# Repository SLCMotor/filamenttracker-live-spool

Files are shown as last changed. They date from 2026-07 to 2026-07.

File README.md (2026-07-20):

# FilamentTracker Live Spool

FilamentTracker Live Spool turns a Raspberry Pi into a local-network spool scale,
NFC/RFID station, touchscreen dashboard, and hardware API for FilamentTracker.
The Android application and FilamentTracker Server remain the inventory systems
of record; Live Spool stores no second spool inventory database.

> [!IMPORTANT]
> Live Spool is designed for a trusted home or workshop LAN. It is not hardened
> for direct Internet exposure. Do not port-forward its API.

## Features

- live spool weight with NAU7802, HX711, or mock scale backends
- PN532 NFC read, verified write, and logical erase operations over I2C
- FilamentTracker JSON/NDEF spool tags and Bambu Lab RFID interoperability
- temporary Android-triggered NFC write sessions
- combined current-spool state without a local inventory database
- touchscreen dashboard, calibration wizard, diagnostics, and settings
- REST API for FilamentTracker Android and FilamentTracker Server
- external configuration and calibration storage designed to survive updates
- idempotent installer, preservation-first updater, and safe uninstaller

## Hardware

Tested appliance:

- Raspberry Pi 5 with 64-bit Raspberry Pi OS Trixie
- ELECROW 7-inch 1024×600 touchscreen
- PN532 NFC reader in I2C mode at `0x24`
- NAU7802 load-cell ADC at `0x2A`
- 5 kg four-wire load cell

Also supported in software:

- HX711 load-cell ADC using BCM GPIO pins (defaults: data 5, clock 6)
- mock hardware on Linux development systems

Raspberry Pi 5 running 64-bit Raspberry Pi OS Trixie is the reference and tested platform. Raspberry Pi 4 with a
64-bit Raspberry Pi OS is expected to work but has not yet received the same
hardware validation. See [Hardware](docs/HARDWARE.md) before wiring anything.

## Hardware documentation

The complete build package is under [`hardware/`](hardware/README.md):

| Guide | Purpose |
| --- | --- |
| [Bill of Materials](hardware/docs/01_Bill_of_Materials.md) | Components, quantities, and build notes |
| [Wiring Diagram](hardware/docs/02_Wiring_Diagram.png) | Raspberry Pi, NFC, scale ADC, and load-cell connections |
| [Assembly Guide](hardware/docs/03_Assembly_Guide.png) | Mechanical assembly overview |
| [Print Plates](hardware/docs/04_Print_Plates.png) | Printable parts and plate organization |
| [Calibration Guide](hardware/docs/05_Calibration_Guide.md) | Tare, calibration, verification, and troubleshooting |

The recommended printable is the multi-plate [`FilamentTracker_Live_Spool.3mf`](hardware/printable/FilamentTracker_Live_Spool.3mf).
An [STL package](hardware/printable/FilamentTracker_Live_Spool_STL.zip) is also
provided for OrcaSlicer, PrusaSlicer, Cura, and other slicers.

The enclosure is modified from MartinNYHC's SpoolBuddy design under CC BY 4.0.
See the [hardware attribution and modification record](hardware/ATTRIBUTION.md).

## Wiring summary

PN532 and NAU7802 intentionally share I2C bus 1:

| Signal | Raspberry Pi | PN532 | NAU7802 |
| --- | --- | --- | --- |
| 3.3 V | Pin 1 or 17 | VCC/VIN* | VCC/VIN* |
| Ground | Any GND | GND | GND |
| SDA1 | GPIO 2 / pin 3 | SDA | SDA |
| SCL1 | GPIO 3 / pin 5 | SCL | SCL |

\* Confirm the voltage requirement printed on your exact breakout board.

Default HX711 wiring:

| HX711 | Raspberry Pi |
| --- | --- |
| VCC | 3.3 V |
| GND | Ground |
| DAT / DOUT | GPIO 5 / pin 29 |
| CLK / SCK | GPIO 6 / pin 31 |

Load-cell wire colors are not universal. For the tested cell, red is `E+`, black
is `E-`, green is `A+`, and white is `A-`. Verify your load-cell datasheet.

## Install

```bash
git clone https://github.com/SLCMotor/filamenttracker-live-spool.git
cd filamenttracker-live-spool
sudo ./install.sh
```

The installer checks the platform, installs system packages, enables I2C, creates
a virtual environment, installs the service and optional kiosk autostart, and
verifies the local API. Existing configuration and calibration are preserved.
New installs use safe mock-hardware defaults; select `nau7802` or `hx711` in:

```text
/etc/filamenttracker-live-spool/config.yaml
```

Then restart:

```bash
sudo systemctl restart live-spool-agent
curl --fail http://127.0.0.1:8001/status
```

Detailed instructions: [Installation](docs/INSTALL.md).

## Configuration

Configuration precedence is environment variables, external YAML, then the
repository development defaults. Appliance files are:

```text
/etc/filamenttracker-live-spool/config.yaml
/etc/filamenttracker-live-spool/live-spool.env
/var/lib/filamenttracker-live-spool/calibration.json
```

Configurable values include device name/location, API host and port, log level,
runtime directory, scale backend and GPIO pins, I2C addresses, development mode,
mock hardware, and local system-control availability. See
[Configuration](docs/CONFIGURATION.md).

## REST API

Common endpoints:

| Method | Path | Purpose |
| --- | --- | --- |
| GET | `/health` | process health without requiring hardware |
| GET | `/status` | combined appliance and hardware status |
| GET | `/weight` | current scale reading |
| GET | `/nfc` | NFC reader and current tag state |
| GET | `/spool/current` | combined live scale and tag snapshot |
| POST | `/nfc/write` | start a temporary verified write session |
| POST | `/nfc/erase` | logically erase a writable NTAG |
| GET/POST | `/calibration/*` | inspect or perform calibration |

Mock routes exist only in development/mock mode. System power routes are disabled
by default. The API intentionally has no cloud discovery or remote-access layer.
See the complete [REST API](docs/API.md) and
[Android integration](docs/ANDROID_INTEGRATION.md).

## Technician menu

On the touchscreen, press and hold the **Filament Tracker / Live Spool** title
in the upper-left corner for about one second. A progress indicator fills during
the 900 ms hold, then the Technician Menu opens.

The menu provides quick access to:

- Dashboard
- Diagnostics
- Calibration
- Settings, including restart, reboot, and shutdown controls

Tap the **×** button or the area outside the menu to close it. The same gesture
works with a mouse by holding the primary button over the title. If the gesture
is unavailable, open `/diagnostics`, `/calibration-wizard`, or `/settings`
directly in the appliance browser.

## Calibration

Open `http://<live-spool-host>:8001/calibration-wizard`, remove all weight, tare,
place an accurately known weight, enter its mass, and verify the result. The
calibration file is written atomically under `/var/lib` and is not overwritten
by installation or updates.

## Photos

<table>
<tr>
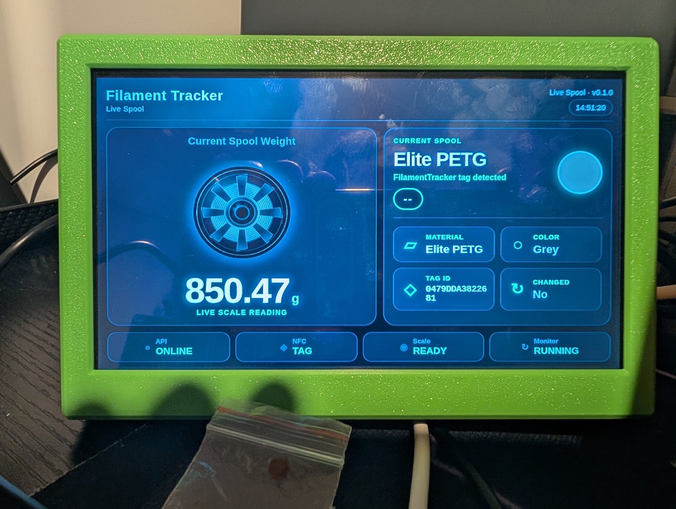
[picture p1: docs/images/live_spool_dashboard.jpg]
Live Spool touchscreen dashboard
<td><br><strong>Touchscreen dashboard</strong></td>
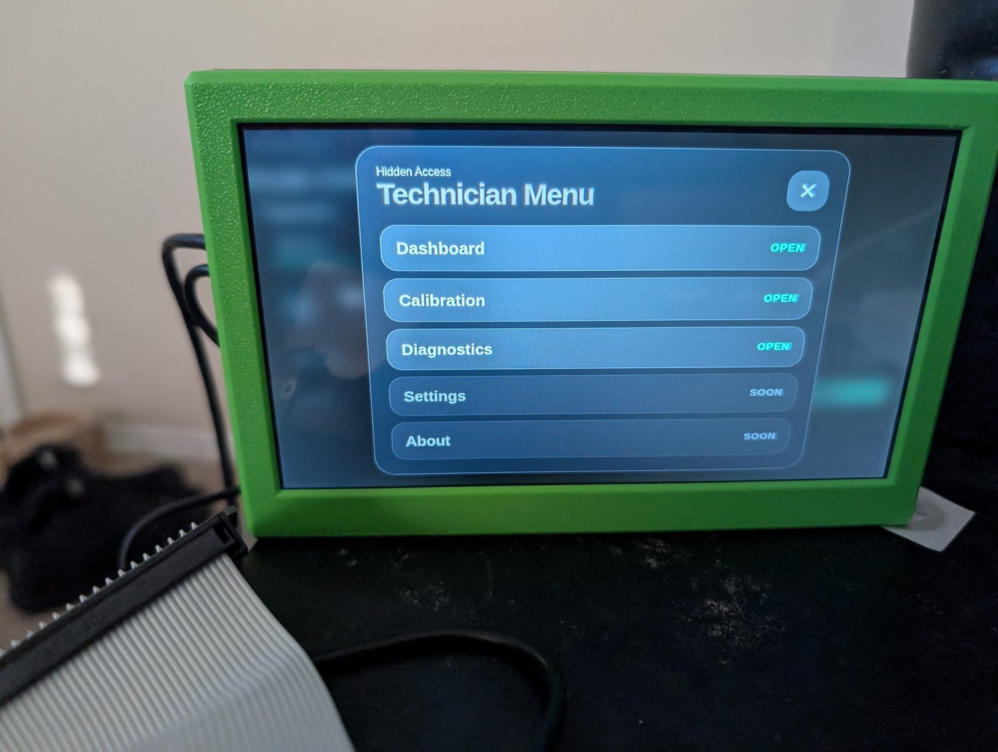
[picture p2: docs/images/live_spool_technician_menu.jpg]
Live Spool technician menu
<td><br><strong>Technician menu</strong></td>
</tr>
<tr>
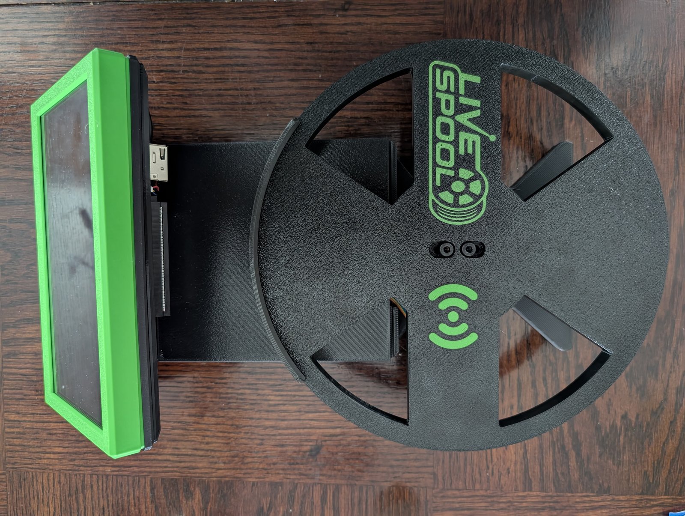
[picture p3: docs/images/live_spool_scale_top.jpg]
Completed Live Spool scale and touchscreen
<td><br><strong>Completed appliance</strong></td>
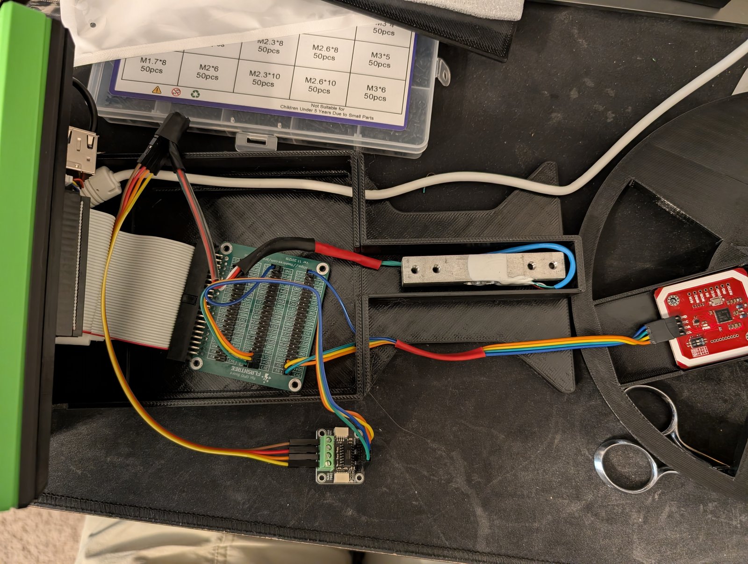
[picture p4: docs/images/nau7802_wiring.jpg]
NAU7802 and PN532 wiring inside the appliance
<td><br><strong>NAU7802 and PN532 wiring</strong></td>
</tr>
</table>

See the [complete hardware gallery](docs/GALLERY.md) for the display, Raspberry Pi,
load cell, PN532, NAU7802, HX711, breakout board, and wiring photographs.
Publication copies are resized and contain no camera EXIF or GPS metadata.

## Updating

```bash
cd filamenttracker-live-spool
sudo ./scripts/update.sh
```

The updater requires a clean checkout, creates a timestamped configuration and
calibration backup, performs a fast-forward-only pull, updates dependencies,
restarts the service, and verifies health. It never pushes changes.

## Troubleshooting

Start with:

```bash
sudo systemctl status live-spool-agent --no-pager -l
sudo journalctl -u live-spool-agent -n 100 --no-pager
i2cdetect -y 1
curl --fail http://127.0.0.1:8001/health
```

Expected I2C addresses are `24` for PN532 and `2a` for NAU7802. See
[Troubleshooting](docs/TROUBLESHOOTING.md).

## Known limitations

- Raspberry Pi 5 is the only fully validated Pi model today.
- The API assumes a trusted LAN and must not be exposed directly to the Internet.
- Bambu RFID support is read-only and depends on successful tag authentication.
- NFC writing targets compatible NTAG/NDEF tags; tag capacity varies.
- Kiosk behavior varies among Raspberry Pi OS desktop/display-server releases.
- Scale accuracy depends heavily on mechanical construction and calibration.

## Roadmap

- validate Raspberry Pi 4 and additional displays
- improve guided hardware selection during installation
- add authentication for optional administrative operations
- expand Android and FilamentTracker Server integration tests
- validate additional enclosure variants and publish editable CAD source when available
- add upgrade rollback assistance and packaged releases

## Contributing and security

See [CONTRIBUTING.md](CONTRIBUTING.md), [SECURITY.md](SECURITY.md), and
[CODE_OF_CONDUCT.md](CODE_OF_CONDUCT.md). Please report security issues privately
rather than opening a public issue.

## License

Software and original project documentation: MIT. See [LICENSE](LICENSE) and
[THIRD_PARTY_NOTICES.md](THIRD_PARTY_NOTICES.md). The derivative printable
enclosure is separately licensed under CC BY 4.0; see
[hardware/ATTRIBUTION.md](hardware/ATTRIBUTION.md).
FilamentTracker and Bambu Lab names belong to their respective owners; this
project is an independent interoperability tool.

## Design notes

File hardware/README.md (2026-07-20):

# FilamentTracker Live Spool Hardware

This directory contains the build documentation and printable enclosure for a
FilamentTracker Live Spool appliance. Start with the bill of materials, follow
the wiring and assembly guides, and calibrate the completed scale before use.

## Hardware documentation

1. [Bill of Materials](docs/01_Bill_of_Materials.md)
2. [Wiring Diagram](docs/02_Wiring_Diagram.png)
3. [Assembly Guide](docs/03_Assembly_Guide.png)
4. [Print Plates](docs/04_Print_Plates.png)
5. [Calibration Guide](docs/05_Calibration_Guide.md)

The wiring, assembly, and print-plate guides are high-resolution images so they
can be viewed directly on GitHub or saved for reference at the workbench.

## Printable files

- [FilamentTracker_Live_Spool.3mf](printable/FilamentTracker_Live_Spool.3mf) —
  recommended multi-plate print project with slicer settings and part placement
- [FilamentTracker_Live_Spool_STL.zip](printable/FilamentTracker_Live_Spool_STL.zip) —
  STL package for OrcaSlicer, PrusaSlicer, Cura, and other slicers
- [FilamentTracker_Live_Spool.stl](printable/FilamentTracker_Live_Spool.stl) —
  unpacked STL supplied for convenient direct import

PETG is recommended for the finished appliance. Review the print-plate guide
and confirm the selected printer, material, and support settings before slicing.

## Build sequence

1. Obtain the components and fasteners in the bill of materials.
2. Print the enclosure from the recommended 3MF project or import the STL.
3. Assemble the enclosure without powering the Raspberry Pi.
4. Wire the PN532, scale ADC, and load cell using the wiring guide.
5. Check every supply voltage and connection before applying power.
6. Install Live Spool using the repository's main installation instructions.
7. Complete tare and calibration using the calibration guide.

Load-cell wire colors and breakout-board voltage requirements are not
universal. Verify the markings and datasheets for the exact parts being used.

## Attribution and licensing

The Live Spool software, wiring documentation, and original project
documentation are licensed separately from the printable enclosure.

The printable enclosure is a modified derivative of the SpoolBuddy enclosure
by MartinNYHC and is distributed under the Creative Commons Attribution 4.0
International license. See [Attribution](ATTRIBUTION.md) and the
[printable-file license notice](printable/LICENSE.md).

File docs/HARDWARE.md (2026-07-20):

# Hardware

Live Spool is designed as a small appliance built around a Raspberry Pi, NFC reader, scale amplifier, load cell, and touchscreen.

For the printable enclosure and illustrated build package, see the
[hardware documentation index](../hardware/README.md).

## Tested Hardware

- Raspberry Pi 5
- 64-bit Raspberry Pi OS Trixie
- 7 inch ELECROW touchscreen
- PN532 NFC reader over I2C
- SparkFun HX711 load cell amplifier
- 5 kg load cell

## Supported Scale Backends

Live Spool currently supports these scale backends:

| Backend | Status | Notes |
| --- | --- | --- |
| `hx711` | Tested | SparkFun HX711 on GPIO 5/6 |
| `nau7802` | Tested on Raspberry Pi 5 | NAU7802 over I2C at default address `0x2A` |
| `mock` | Tested | Development and UI testing |

## PN532 NFC Reader

The current PN532 implementation uses I2C.

Typical Raspberry Pi I2C pins:

| PN532 | Raspberry Pi |
| --- | --- |
| VIN / VCC | 3.3V or board-supported power input |
| GND | GND |
| SDA | GPIO 2 / SDA1 |
| SCL | GPIO 3 / SCL1 |

Enable I2C on the Pi if it is not already enabled.

```bash
sudo raspi-config
```

Then use Interface Options to enable I2C.

The code currently initializes the PN532 at I2C address `0x24`.

## HX711 Scale

The current tested HX711 GPIO wiring is:

| HX711 | Raspberry Pi |
| --- | --- |
| VDD / VCC | 3.3V |
| GND | GND |
| DAT | GPIO 5 |
| CLK | GPIO 6 |

Corresponding config:

```yaml
scale:
  backend: "hx711"
  mock: false
  hx711:
    data_pin: 5
    clock_pin: 6
    gain: 128
    samples: 15
```

Use 3.3V for Pi GPIO logic compatibility.

## Load Cell Wiring

For the tested 4-wire load cell:

| Load cell wire | HX711 |
| --- | --- |
| Red | E+ |
| Black | E- |
| White | A- |
| Green | A+ |

If the load cell has a yellow shield wire, leave it unconnected unless your load cell documentation says otherwise.

If weight increases in the wrong direction, swap `A+` and `A-`.

## Calibration

### Open the technician menu

Press and hold the **Filament Tracker / Live Spool** title in the upper-left
corner of the touchscreen for about one second. When the hold indicator
completes, select **Calibration**. The same menu also provides Dashboard,
Diagnostics, and Settings shortcuts.

Calibration can be started from:

- the dashboard Calibrate shortcut
- the technician menu
- `/calibration-wizard`

Recommended flow:

1. Remove all weight from the scale.
2. Tare the scale.
3. Place a known weight on the scale.
4. Enter the known weight in grams.
5. Save calibration.
6. Verify with the same known weight.

Calibration data is saved on installed appliances under:

```text
/var/lib/filamenttracker-live-spool/calibration.json
```

## NAU7802 Scale

NAU7802 support is implemented with direct I2C register access. Your `i2cdetect`
scan should show the NAU7802 at address `0x2A`.

Typical Raspberry Pi I2C wiring:

| NAU7802 | Raspberry Pi |
| --- | --- |
| VIN / VCC | 3.3V |
| GND | GND |
| SDA | GPIO 2 / SDA1 |
| SCL | GPIO 3 / SCL1 |

Load cell wiring is the same bridge layout as HX711 boards:

| Load cell wire | NAU7802 |
| --- | --- |
| Red | E+ |
| Black | E- |
| White | A- |
| Green | A+ |

Corresponding config:

```yaml
scale:
  backend: "nau7802"
  mock: false
  nau7802:
    address: 0x2A
    channel: 1
    gain: 128
    poll_rate: 10
    samples: 15
    stable_stddev: 1000
```

The Android app does not need to care which scale backend the Pi uses.

## Photographs

See the [hardware gallery](GALLERY.md) for publication-safe photographs of the completed appliance, display enclosure, Raspberry Pi 5, load cell, PN532, NAU7802, HX711, GPIO breakout, and installed wiring.

## Printable enclosure

Use the [3MF print project](../hardware/printable/FilamentTracker_Live_Spool.3mf)
for the recommended plate layout or the
[STL package](../hardware/printable/FilamentTracker_Live_Spool_STL.zip) with
another slicer. Build guides and licensing details are maintained under
[`hardware/`](../hardware/README.md).

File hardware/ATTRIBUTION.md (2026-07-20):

# Printable Hardware Attribution

## Original design

- **Author:** MartinNYHC (Martin Ziegler)
- **Project:** SpoolBuddy enclosure
- **MakerWorld source:** [SpoolBuddy model 2296982](https://makerworld.com/en/models/2296982-spoolbuddy)
- **Official project:** [Bambuddy / SpoolBuddy](https://github.com/maziggy/bambuddy)
- **Official build documentation:** [SpoolBuddy Assembly Guide](https://wiki.bambuddy.cool/spoolbuddy/assembly/)
- **License:** [Creative Commons Attribution 4.0 International](https://creativecommons.org/licenses/by/4.0/)

MakerWorld identifies MartinNYHC as the design creator and the model license as
Creative Commons Attribution (`BY`). The AGPL-3.0 license used by the Bambuddy
software repository does not govern the Live Spool software or replace the CAD
model's Creative Commons license.

## FilamentTracker Live Spool modifications

The STL geometry in this repository is a modified version prepared for the
FilamentTracker Live Spool hardware platform. The 3MF print project packages
that derivative geometry with print-plate and slicer configuration.

Changes from the original enclosure include:

- replaced the original branding with the Live Spool logo
- increased the main enclosure's internal dimensions for wiring and electronics
- raised the touchscreen position for Raspberry Pi 5 active-cooler clearance
- increased clearance for NVMe/SSD HATs and future expansion hardware
- opened the rear section of the display cover for airflow and larger hardware
- refined the enclosure for the FilamentTracker Live Spool component layout

These changes are identified as modifications and are not endorsed by or
affiliated with the original SpoolBuddy project.

## Scope

This attribution and the CC BY 4.0 license apply only to the derivative
printable enclosure files in `hardware/printable/`. FilamentTracker Live Spool's
independently developed software remains under the repository's MIT License.

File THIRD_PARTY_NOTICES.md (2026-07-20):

# Third-Party Notices

FilamentTracker Live Spool is distributed under the MIT License. It installs
third-party Python packages that remain under their respective licenses. The
following inventory was resolved from `software/pi-agent/requirements.txt` for
version 0.1.0. Package source distributions and license texts are available
from the linked upstream projects and from PyPI.

| Package | Version | License |
| --- | ---: | --- |
| Adafruit-Blinka | 9.1.0 | MIT |
| Adafruit-Blinka-Raspberry-Pi5-Neopixel | 1.0.0rc2 | GPL-2.0-only |
| Adafruit-PlatformDetect | 3.89.1 | MIT |
| Adafruit-PureIO | 1.1.11 | MIT |
| adafruit-circuitpython-busdevice | 5.2.17 | MIT |
| adafruit-circuitpython-connectionmanager | 3.1.8 | MIT |
| adafruit-circuitpython-pn532 | 2.4.9 | MIT |
| adafruit-circuitpython-requests | 4.1.17 | MIT |
| adafruit-circuitpython-typing | 1.12.3 | MIT |
| annotated-doc | 0.0.4 | MIT |
| annotated-types | 0.7.0 | MIT |
| anyio | 4.14.1 | MIT |
| binho-host-adapter | 0.1.6 | MIT |
| click | 8.4.2 | BSD-3-Clause |
| colorzero | 2.0 | BSD-3-Clause |
| FastAPI | 0.138.1 | MIT |
| gpiozero | 2.0.1 | BSD-3-Clause |
| h11 | 0.16.0 | MIT |
| idna | 3.18 | BSD-3-Clause |
| Jinja2 | 3.1.6 | BSD-3-Clause |
| lgpio | 0.2.2.0 | Unlicense |
| MarkupSafe | 3.0.3 | BSD-3-Clause |
| Pydantic | 2.13.4 | MIT |
| pydantic-core | 2.46.4 | MIT |
| pyftdi | 0.57.2 | BSD-3-Clause |
| pyserial | 3.5 | BSD-3-Clause |
| pyusb | 1.3.1 | BSD-3-Clause |
| PyYAML | 6.0.3 | MIT |
| RPi.GPIO | 0.7.1 | MIT |
| rpi-ws281x | 5.0.0 | MIT |
| setuptools | 83.0.0 | MIT |
| Starlette | 1.3.1 | BSD-3-Clause |
| sysv-ipc | 1.2.0 | BSD-3-Clause |
| typing-extensions | 4.15.0 | PSF-2.0 |
| typing-inspection | 0.4.2 | MIT |
| Uvicorn | 0.49.0 | BSD-3-Clause |

Raspberry Pi 5 installations pull `Adafruit-Blinka-Raspberry-Pi5-Neopixel` as a platform-specific Blinka dependency. It is licensed under GPL version 2; its corresponding source and license are available at https://github.com/adafruit/Adafruit_Blinka_Raspberry_Pi5_Neopixel. Anyone redistributing a prepared appliance image must preserve that license and satisfy its source-code requirements. The project installer downloads this package from PyPI and does not vendor it in this repository.

The authoritative license text shipped with each installed Python distribution
takes precedence over this summary. The installer does not copy third-party
source into this repository.

## Upstream projects

- Adafruit CircuitPython libraries: https://github.com/adafruit
- FastAPI: https://github.com/fastapi/fastapi
- Pydantic: https://github.com/pydantic/pydantic
- Starlette: https://github.com/Kludex/starlette
- Uvicorn: https://github.com/Kludex/uvicorn
- gpiozero: https://github.com/gpiozero/gpiozero
- Jinja2: https://github.com/pallets/jinja
- lgpio: https://github.com/joan2937/lg
- typing-extensions: https://github.com/python/typing_extensions

Bambu Lab is a trademark of its respective owner. Bambu RFID compatibility is
an independent interoperability feature and is not endorsed by or affiliated
with Bambu Lab.

## Printable enclosure design

The printable enclosure under `hardware/printable/` is a modified derivative
of the SpoolBuddy enclosure by MartinNYHC. The source model is published on
[MakerWorld](https://makerworld.com/en/models/2296982-spoolbuddy) under the
[Creative Commons Attribution 4.0 International License](https://creativecommons.org/licenses/by/4.0/).
The attribution, modification summary, and exact license scope are documented
in [`hardware/ATTRIBUTION.md`](hardware/ATTRIBUTION.md). This Creative Commons
license applies to the derivative printable geometry, not to the independently
developed FilamentTracker Live Spool software.

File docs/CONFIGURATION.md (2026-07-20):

# Configuration

Appliance configuration lives outside the Git checkout so updates cannot replace
hardware choices or calibration.

## Files and precedence

1. `LIVE_SPOOL_*` environment variables
2. `/etc/filamenttracker-live-spool/config.yaml`
3. `software/pi-agent/config/config.yaml` for development fallback

The systemd service reads `/etc/filamenttracker-live-spool/live-spool.env`.
Restart the service after changes.

## Environment variables

| Variable | Meaning | Default |
| --- | --- | --- |
| `LIVE_SPOOL_CONFIG_FILE` | YAML file path | system file when present |
| `LIVE_SPOOL_DATA_DIR` | calibration/runtime directory | application `data/` |
| `LIVE_SPOOL_DEVICE_NAME` | advertised device name | `Live Spool` |
| `LIVE_SPOOL_DEVICE_LOCATION` | optional display location | empty |
| `LIVE_SPOOL_API_HOST` | bind address | `0.0.0.0` |
| `LIVE_SPOOL_API_PORT` | HTTP port | `8001` |
| `LIVE_SPOOL_LOG_LEVEL` | Uvicorn log level | `info` |
| `LIVE_SPOOL_SCALE_BACKEND` | `mock`, `nau7802`, or `hx711` | YAML value |
| `LIVE_SPOOL_HX711_DATA_PIN` | BCM data pin | `5` |
| `LIVE_SPOOL_HX711_CLOCK_PIN` | BCM clock pin | `6` |
| `LIVE_SPOOL_NAU7802_ADDRESS` | decimal or `0x` address | `0x2A` |
| `LIVE_SPOOL_PN532_ADDRESS` | decimal or `0x` address | `0x24` |
| `LIVE_SPOOL_DEVELOPMENT_MODE` | expose development behavior | `false` appliance |
| `LIVE_SPOOL_MOCK_HARDWARE` | force all mock devices | `false` appliance |
| `LIVE_SPOOL_SYSTEM_CONTROLS_ENABLED` | expose local appliance controls | `true` on installed appliances |

Boolean values accept `true/false`, `yes/no`, `on/off`, and `1/0`.

## Real NAU7802 example

Set `hardware.device_mode` to `real`, `scale.backend` to `nau7802`, both
`scale.mock` and `nfc.mock` to `false`, and retain PN532 address `0x24`.

## Real HX711 example

Use the same real NFC settings, set `scale.backend` to `hx711`, and configure the
BCM GPIO pins under `scale.hx711`.

System controls are disabled in development defaults and enabled for new
appliance installations. The installer grants the appliance user only the
commands required to restart Live Spool, reboot, and power off. These local
controls do not add authentication and must never be exposed directly to the
Internet.

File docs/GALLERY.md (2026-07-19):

# Hardware Gallery

These publication copies are resized and have camera EXIF and GPS metadata removed.
Wire colors are shown for reference only; always verify signals against the board
labels and the load-cell manufacturer's documentation.

## Completed appliance and interface

| Appliance | Interface |
| --- | --- |
| Completed Live Spool scale | Live Spool dashboard |
| Top view of the completed scale and touchscreen. | Dashboard showing live weight, spool details, scale, and NFC state. |
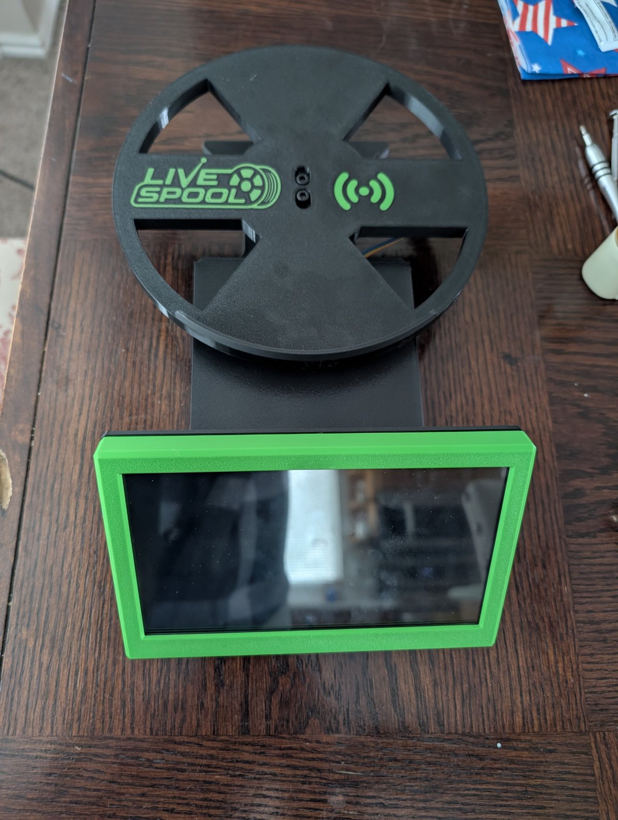
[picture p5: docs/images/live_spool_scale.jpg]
Live Spool scale and separate spool platform
|  | Technician menu |
| Display and spool platform. | Touch-friendly technician menu. |

## Display and Raspberry Pi 5

| Rear enclosure | Installed Pi 5 |
| --- | --- |
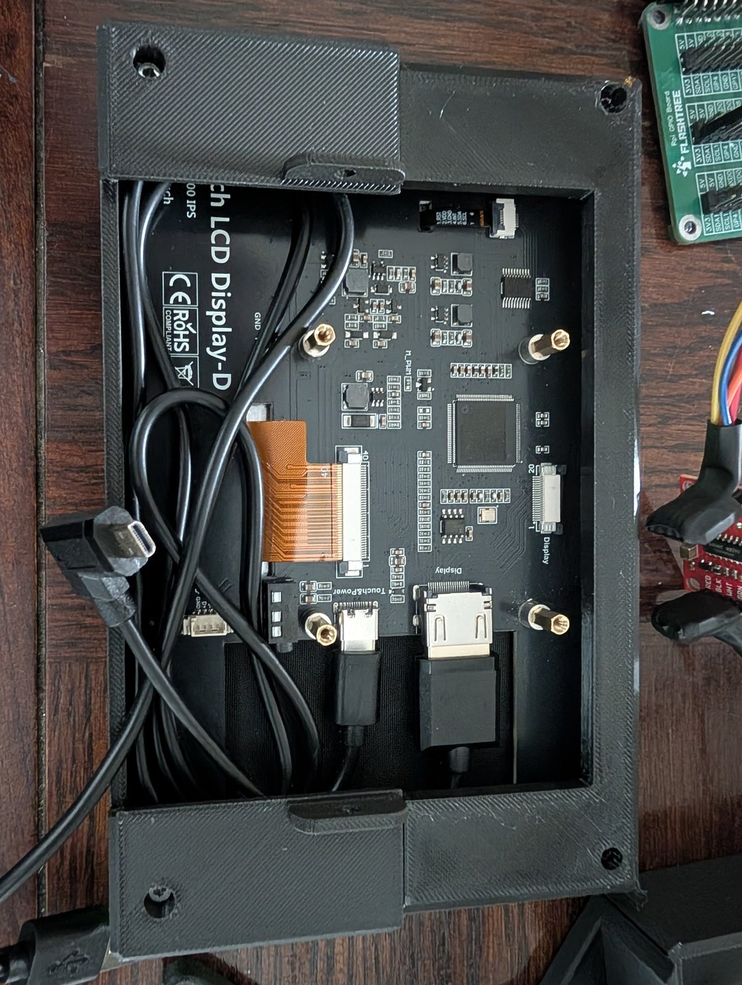
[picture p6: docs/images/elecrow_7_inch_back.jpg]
Rear of ELECROW seven-inch display
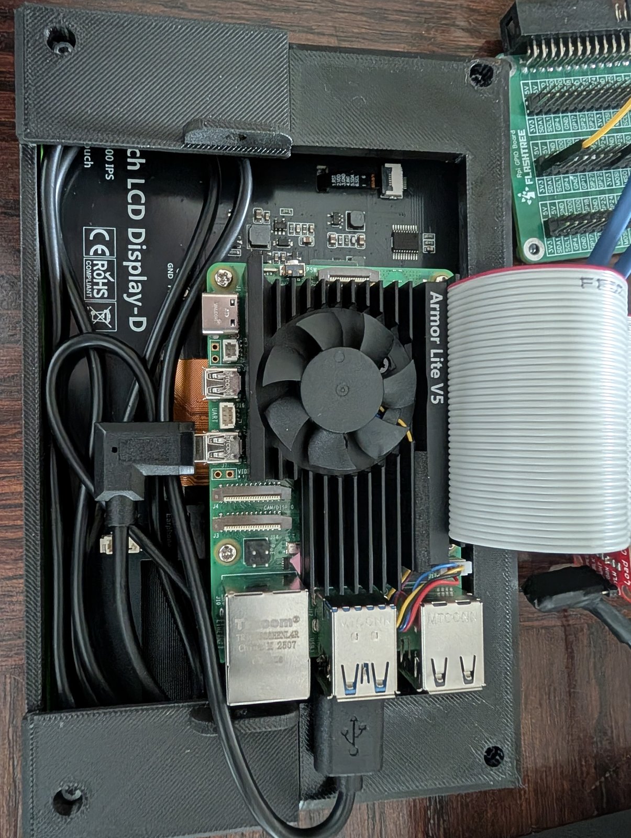
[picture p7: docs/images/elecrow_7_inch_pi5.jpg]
Raspberry Pi 5 installed behind the display
|  |  |
| Display electronics and mounting enclosure. | Raspberry Pi 5, cooling, cabling, and GPIO ribbon cable. |

## PN532 and NAU7802

| Component | Installed wiring |
| --- | --- |
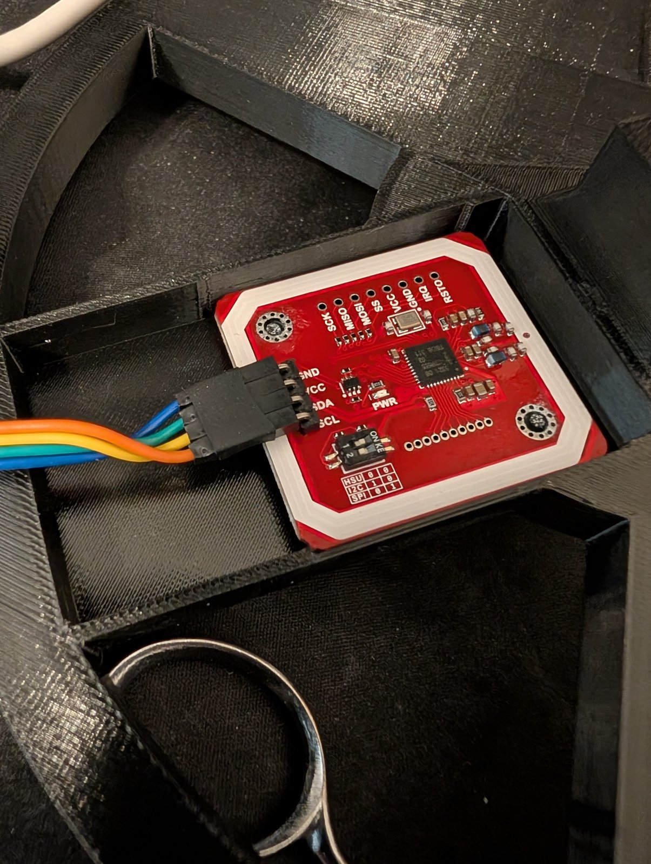
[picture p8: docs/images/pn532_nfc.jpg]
PN532 NFC reader
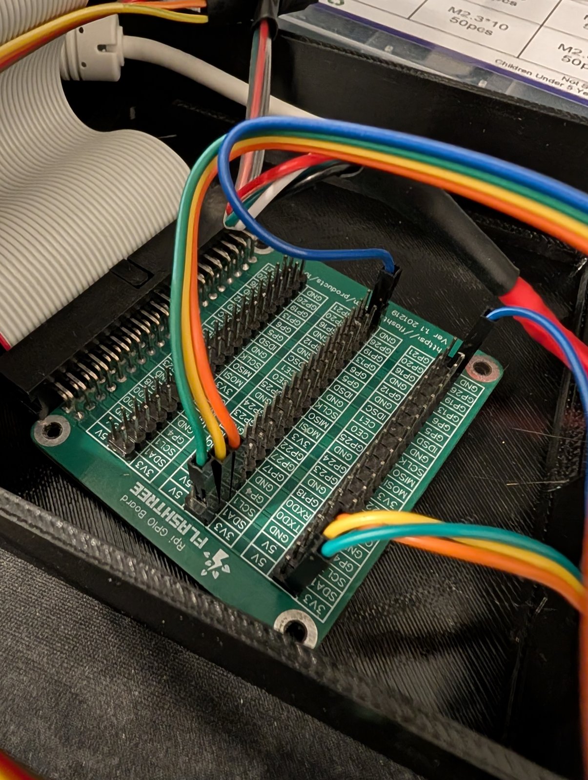
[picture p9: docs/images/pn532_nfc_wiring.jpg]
PN532 wiring
|  |  |
| PN532 configured for I2C. | PN532 connected through the GPIO breakout. |
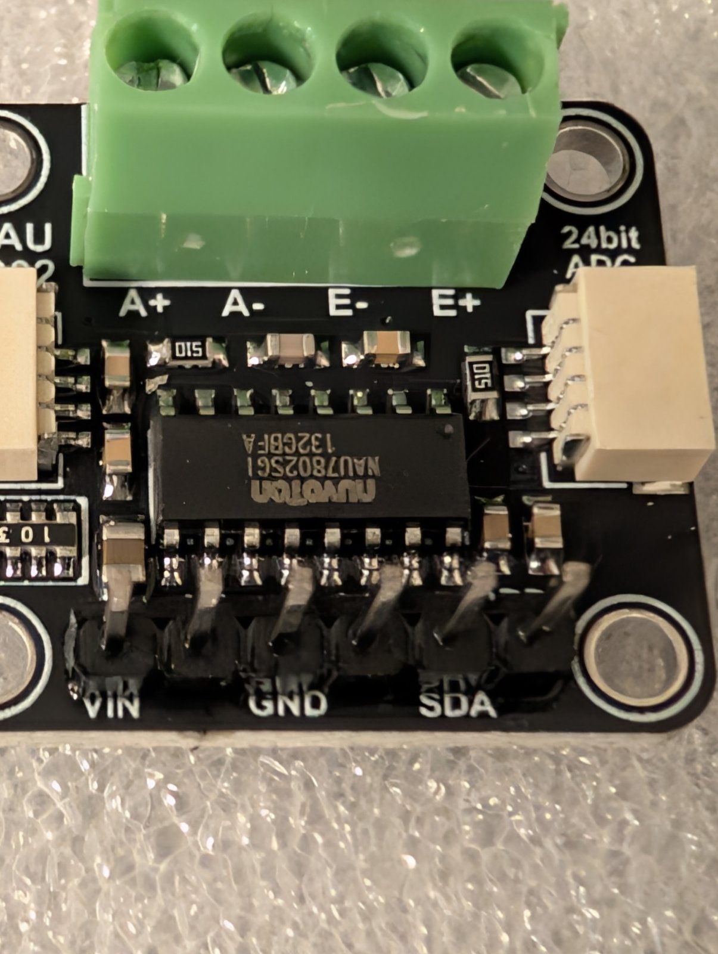
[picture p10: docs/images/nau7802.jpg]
NAU7802 load-cell ADC
|  | NAU7802 wiring |
| NAU7802 bridge input and I2C terminals. | NAU7802, load-cell conductors, and shared I2C wiring. |

## HX711 alternative

| Load cell | HX711 installation |
| --- | --- |
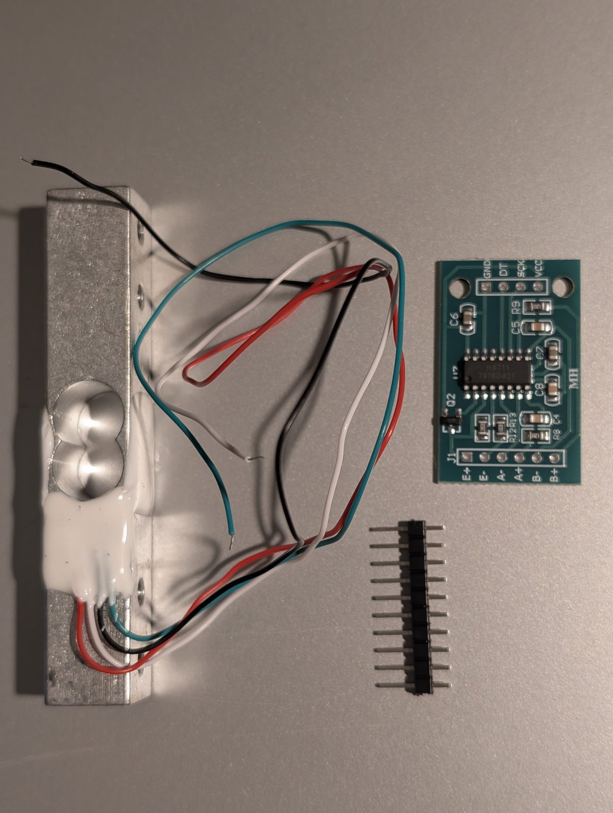
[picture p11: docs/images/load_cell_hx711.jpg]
Load cell and HX711 parts
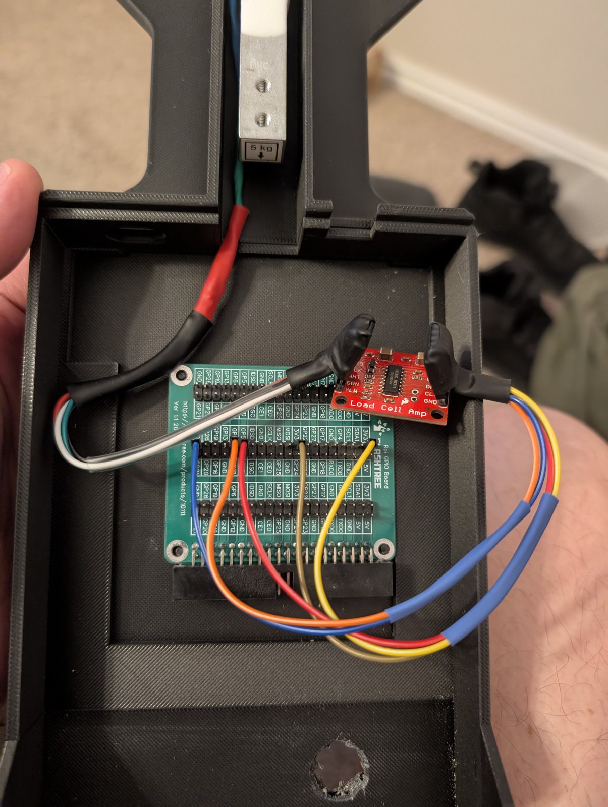
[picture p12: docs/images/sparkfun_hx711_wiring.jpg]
SparkFun HX711 installed
|  |  |
| Four-wire load cell, mounting hardware, and header. | HX711 alternative wired inside the base. |
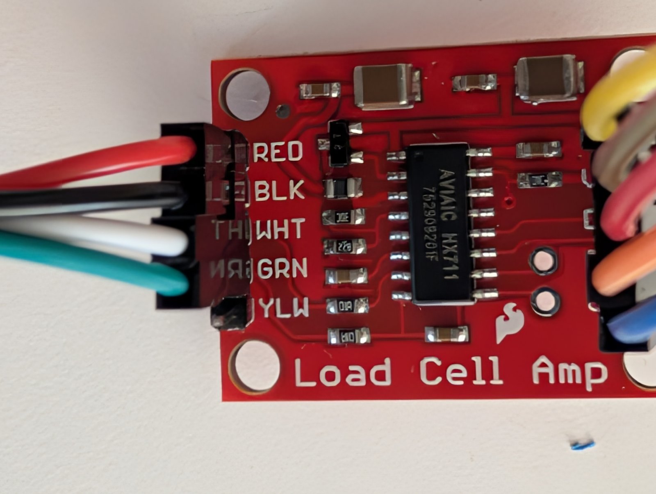
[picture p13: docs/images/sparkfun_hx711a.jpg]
SparkFun HX711 load-cell side
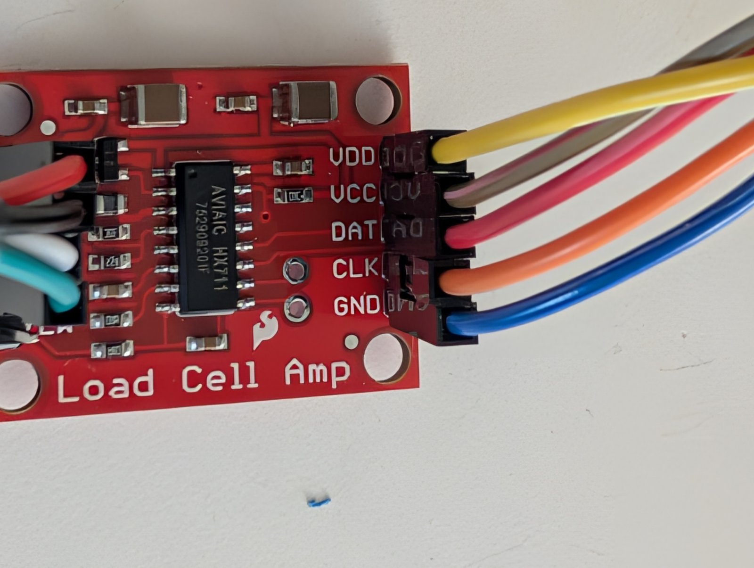
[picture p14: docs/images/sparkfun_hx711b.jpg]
SparkFun HX711 Raspberry Pi side
|  |  |
| Load-cell signal labels. | Power, data, and clock labels. |

## GPIO breakout

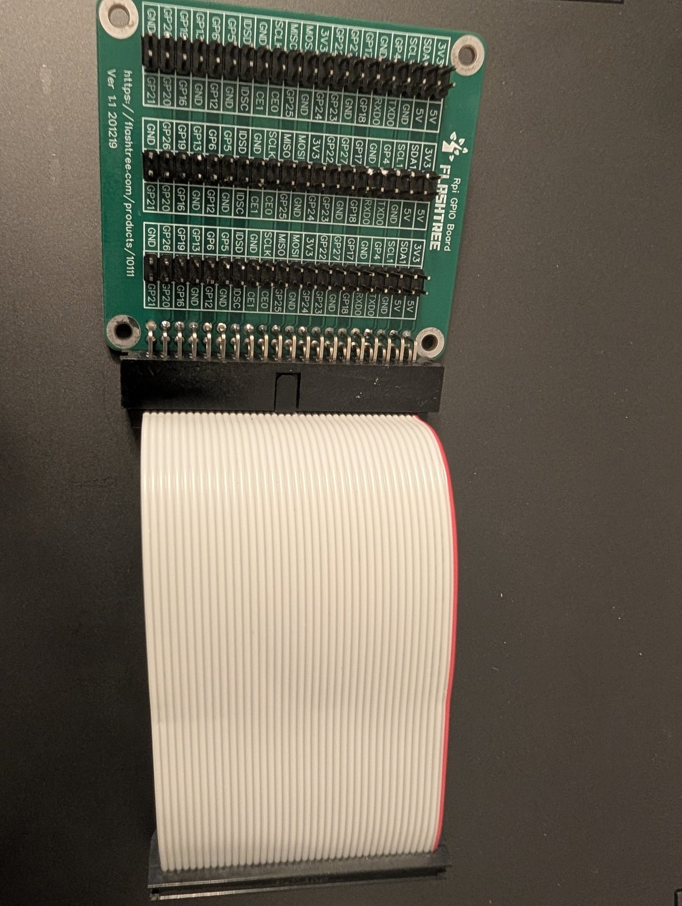
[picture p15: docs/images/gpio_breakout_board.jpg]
GPIO ribbon-cable breakout board


The breakout board provides accessible Raspberry Pi GPIO and I2C connections inside
the display enclosure.

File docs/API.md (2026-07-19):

# API

Live Spool exposes a local HTTP API on port `8001`.

Example base URL:

```text
http://<live-spool-ip>:8001
```

## Status

```http
GET /status
```

Returns overall API, scale, NFC, CPU temperature, and uptime.

Example:

```json
{
  "status": "online",
  "deviceName": "Live Spool",
  "version": "0.1.0",
  "scale": {
    "connected": true,
    "stable": true,
    "weightGrams": 1000.93
  },
  "nfc": {
    "connected": true,
    "tagPresent": false,
    "tagId": null,
    "data": null,
    "tag": null,
    "tagType": null,
    "bambu": null,
    "error": null
  },
  "cpuTempC": 54.0,
  "uptime": "58m"
}
```

## Weight

```http
GET /weight
```

Returns the scale status.

Example:

```json
{
  "connected": true,
  "stable": true,
  "weightGrams": 1000.93
}
```

## NFC

```http
GET /nfc
```

Returns the current NFC reader state.

FilamentTracker tag example:

```json
{
  "connected": true,
  "tagPresent": true,
  "tagId": "0479DDA3822681",
  "data": "{\"app\":\"FT\",\"ver\":1,\"type\":\"spool\"}",
  "tag": {
    "app": "FT",
    "ver": 1,
    "type": "spool",
    "spoolId": "b85d04fc-bcb0-4d84-8b0f-29ff79d6e9cd",
    "filamentId": "6666d29d-47f4-4ced-9818-2dc9bbeb1724",
    "brand": "Creality",
    "material": "Hyper PLA",
    "colorName": "Gray",
    "colorHex": "#808080",
    "initialGrams": 1000,
    "remainingGrams": 200.52,
    "updatedAtEpochMs": 1780000000000
  },
  "tagType": "filamenttracker",
  "bambu": null,
  "error": null
}
```

Bambu Lab RFID tag example:

```json
{
  "connected": true,
  "tagPresent": true,
  "tagId": "01B76103",
  "tag": {
    "app": "Bambu Lab",
    "type": "rfid",
    "uid": "01B76103",
    "brand": "Bambu Lab",
    "material": "PLA",
    "variant": "PLA Basic",
    "filamentCode": "A00-G06",
    "colorHex": "#00AE42",
    "spoolWeightG": 1000
  },
  "tagType": "bambu_lab_rfid",
  "bambu": {
    "isBambuTag": true,
    "uid": "01B76103",
    "authenticatedSectorCount": 16,
    "readBlockCount": 48,
    "parseWarnings": []
  },
  "error": null
}
```

## Erase NFC Tag

```http
POST /nfc/erase
```

Performs a logical erase of a writable NTAG by replacing user data with an empty NDEF message.

## Write NFC Tag

```http
POST /nfc/write
```

Starts an NFC write session. The request is temporary and is discarded after the write succeeds, fails, is canceled, or times out.

Request:

```json
{
  "requestId": "android-unique-request-id",
  "timeoutSeconds": 60,
  "payload": {
    "app": "FT",
    "ver": 1,
    "type": "spool",
    "spoolId": "b85d04fc-bcb0-4d84-8b0f-29ff79d6e9cd",
    "filamentId": "6666d29d-47f4-4ced-9818-2dc9bbeb1724",
    "brand": "Creality",
    "material": "Hyper PLA",
    "colorName": "Gray",
    "colorHex": "#808080",
    "initialGrams": 1000,
    "remainingGrams": 200.52,
    "updatedAtEpochMs": 1780000000000
  },
  "display": {
    "locationName": "Filament Rack"
  }
}
```

Response:

```json
{
  "requestId": "android-unique-request-id",
  "state": "ready",
  "message": "Ready to Write",
  "tagId": null,
  "errorCode": null,
  "payload": {},
  "display": {},
  "startedAt": "2026-07-03T04:43:02.170112+00:00",
  "updatedAt": "2026-07-03T04:43:02.170112+00:00",
  "finishedAt": null
}
```

Write states:

| State | Meaning |
| --- | --- |
| `ready` | Waiting for a tag |
| `writing` | Writing the payload |
| `verifying` | Reading back and checking the payload |
| `succeeded` | Write and verification succeeded |
| `failed` | Write failed |
| `timed_out` | No writable tag was completed before timeout |
| `canceled` | Request was canceled |
| `idle` | No active request |

Poll current write session:

```http
GET /nfc/write/current
```

Poll by request ID:

```http
GET /nfc/write/{requestId}
```

Cancel:

```http
DELETE /nfc/write/{requestId}
```

## Current Spool State

```http
GET /spool/current
```

Returns combined scale and NFC state for the dashboard and Android workflows.

Important fields:

| Field | Meaning |
| --- | --- |
| `loaded` | True when a FilamentTracker spool is recognized |
| `weightGrams` | Current live scale reading |
| `tagPresent` | True when any NFC/RFID tag is present |
| `tagId` | Current tag UID |
| `spool` | Parsed FilamentTracker spool payload, if available |
| `nfc` | Raw NFC status |
| `scale` | Raw scale status |
| `tagWeightGrams` | `remainingGrams` read from the NFC tag |
| `weightDeltaGrams` | Live scale minus tag weight snapshot |
| `tagWeightChanged` | True when delta exceeds tolerance |
| `weightToleranceGrams` | Current comparison tolerance |

## Calibration

```http
GET /calibration/status
POST /calibration/tare
POST /calibration/known-weight
POST /calibration/reset
```

Known weight request:

```json
{
  "knownWeightGrams": 1000
}
```

## UI Pages

```text
/dashboard
/diagnostics
/settings
/settings/scale
/settings/nfc
/settings/network
/settings/display
/settings/about
/calibration-wizard
```

## Process Health

```http
GET /health
```

Returns application process health and version without requiring the scale or NFC
reader to be connected. Use `/status` when hardware state is also required.

## Local-network security

The API is intended only for a trusted LAN and must not be exposed directly to
the Internet. Mock endpoints are registered only in development/mock mode.
`/system/*` routes are disabled unless `system_controls_enabled` is deliberately
set. Enabling those routes does not add authentication or Internet hardening.

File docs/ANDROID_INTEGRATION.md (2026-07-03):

# Android Integration

FilamentTracker Android is the master database. Live Spool is a local hardware appliance.

The integration rule is:

```text
Android owns inventory.
Live Spool reports hardware state and performs temporary NFC write jobs.
```

## Android Settings

In FilamentTracker Android:

1. Open Settings.
2. Enable Live Spool integration.
3. Enter the Live Spool API URL:

```text
http://<live-spool-ip>:8001
```

4. Tap Test Connection.

If the connection succeeds, Android can:

- read Live Spool scale weight
- send NFC write jobs to the Pi
- update a spool after user confirmation
- rewrite NFC tags with updated weight snapshots

## Spool NFC Writing

Android supports two spool-specific NFC write paths:

- Phone NFC
- Live Spool NFC

Both write the same FilamentTracker spool payload. The difference is which device writes the tag.

### Phone NFC

1. Open a filament.
2. Find the target spool card.
3. Tap Phone NFC.
4. Hold a writable NFC tag to the phone.

### Live Spool NFC

1. Open a filament.
2. Find the target spool card.
3. Tap Live Spool NFC.
4. Android sends `POST /nfc/write` to the Pi.
5. Live Spool switches to its write screen.
6. Place a writable NFC tag on the Pi reader.
7. Live Spool writes, verifies, and returns to the dashboard.
8. Android receives success or failure.

## Payload Schema

Recommended spool payload:

```json
{
  "app": "FT",
  "ver": 1,
  "type": "spool",
  "spoolId": "b85d04fc-bcb0-4d84-8b0f-29ff79d6e9cd",
  "filamentId": "6666d29d-47f4-4ced-9818-2dc9bbeb1724",
  "brand": "Creality",
  "material": "Hyper PLA",
  "colorName": "Gray",
  "colorHex": "#808080",
  "initialGrams": 1000,
  "remainingGrams": 200.52,
  "updatedAtEpochMs": 1780000000000
}
```

Required minimum fields:

- `app`: `FT`
- `ver`: payload version, currently `1`
- `type`: `spool`
- `spoolId`
- `filamentId`

Optional but useful fields:

- `brand`
- `material`
- `colorName`
- `colorHex`
- `initialGrams`
- `remainingGrams`
- `updatedAtEpochMs`

The tag is a snapshot. It should not be treated as the source of truth.

## Weight Update Workflow

Recommended appliance workflow:

1. Place tagged spool on Live Spool.
2. Live Spool reads the tag and live scale weight.
3. Live Spool compares live weight to tag `remainingGrams`.
4. If the values differ beyond tolerance, Live Spool displays the change.
5. In Android, open that spool and tap Update Weight from Live Spool.
6. Android shows current saved weight, detected weight, and difference.
7. User confirms.
8. Android saves the new remaining grams.
9. Android offers to rewrite the NFC tag.
10. User chooses Phone NFC or Live Spool NFC.

This keeps Android authoritative while still making the Pi feel automatic.

## Error Handling

Android should handle:

- Pi unavailable
- scale disconnected
- NFC reader disconnected
- writer busy
- write timeout
- verification failure
- user cancellation

Live Spool write states:

- `ready`
- `writing`
- `verifying`
- `succeeded`
- `failed`
- `timed_out`
- `canceled`

Android should poll `GET /nfc/write/{requestId}` or `GET /nfc/write/current` until a terminal state is reached.

Terminal states:

- `succeeded`
- `failed`
- `timed_out`
- `canceled`

## Important Design Notes

- Live Spool should not maintain a spool database.
- Live Spool should not decide inventory changes.
- Live Spool may display weight differences.
- Android should approve and save inventory changes.
- Android should decide whether to rewrite the NFC tag.

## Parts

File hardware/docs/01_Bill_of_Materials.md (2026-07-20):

# Bill of Materials

This list covers the reference FilamentTracker Live Spool appliance. Equivalent
components can be used when their electrical and mechanical specifications are
compatible.

## Core components

| Component | Quantity | Purpose and notes |
| --- | ---: | --- |
| Raspberry Pi 5, 4 GB or 8 GB | 1 | Main controller; Raspberry Pi 4 is expected to work but is not as thoroughly validated |
| ELECROW 7-inch 1024×600 touchscreen | 1 | Local kiosk interface |
| PN532 NFC reader configured for I2C | 1 | Reads and writes FilamentTracker NFC tags; default address `0x24` |
| NAU7802 load-cell ADC | 1 | Recommended scale interface; default address `0x2A` |
| 5 kg four-wire load cell | 1 | Weight sensor |
| microSD card, 32 GB minimum | 1 | Raspberry Pi OS and Live Spool; 64–256 GB is recommended |
| Raspberry Pi USB-C power supply, 5 V/5 A | 1 | Use the official supply or an equivalent high-quality unit |
| NTAG215 NFC tags | As needed | Filament spool identification; compatible NTAG213/216 tags can also be used when capacity permits |

## Recommended and optional components

| Component | Quantity | Purpose and notes |
| --- | ---: | --- |
| Raspberry Pi GPIO breakout board | 1 | Recommended for cleaner wiring, maintenance, and future expansion |
| Raspberry Pi 5 active cooler | 1 | Recommended for sustained appliance use |
| HX711 load-cell ADC | 1 | Optional alternative to the NAU7802; software support is retained |
| NVMe/SSD HAT and drive | 1 | Optional storage expansion supported by the enlarged enclosure |
| M2.5 and M3 fasteners | As needed | Screws, threaded inserts, and standoffs for the selected components |
| M4 × 25 mm screws | 4 | Load-cell and platform mounting; confirm against your printed parts |
| Rubber feet | 4 | Keeps the scale stable and helps isolate vibration |
| Hookup wire and connectors | As needed | Use secure, appropriately sized connections |

## Before ordering

- Confirm the touchscreen model and mounting dimensions. Similar-looking
  seven-inch displays are not necessarily mechanically interchangeable.
- Confirm the PN532 breakout supports I2C and the voltage printed on the board.
- Confirm the NAU7802 or HX711 input and supply requirements.
- Check the load cell's rated capacity, hole spacing, physical dimensions, and
  wiring documentation. Wire colors are not standardized.
- Compare fastener requirements with the current print project before ordering.

## Build notes

- PN532 and NAU7802 intentionally share Raspberry Pi I2C bus 1.
- The reference addresses are `0x24` for PN532 and `0x2A` for NAU7802.
- Do not apply power until supply, ground, SDA, and SCL connections have been
  checked against the [wiring diagram](02_Wiring_Diagram.png).
- The [3MF project](../printable/FilamentTracker_Live_Spool.3mf) is the
  recommended printable; an [STL package](../printable/FilamentTracker_Live_Spool_STL.zip)
  is available for other slicers.

## Enclosure attribution

The printable enclosure is modified from the
[SpoolBuddy enclosure by MartinNYHC](https://makerworld.com/en/models/2296982-spoolbuddy)
under the [Creative Commons Attribution 4.0 International License](https://creativecommons.org/licenses/by/4.0/).
See the complete [attribution and modification record](../ATTRIBUTION.md).

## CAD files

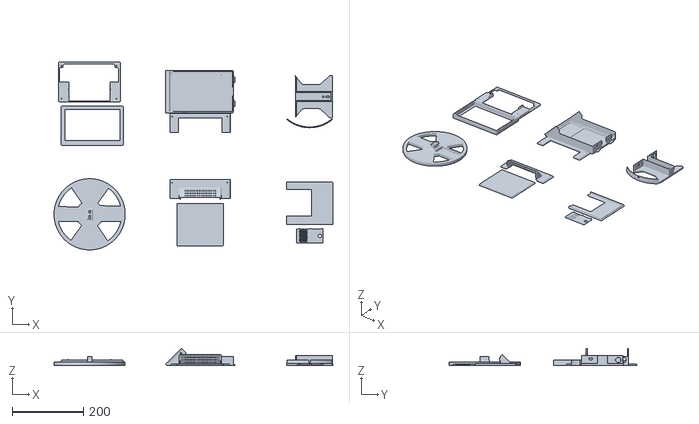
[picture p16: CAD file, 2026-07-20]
hardware/printable/FilamentTracker_Live_Spool.stl
783.3 x 527.2 x 48.8

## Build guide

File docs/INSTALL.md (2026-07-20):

# Installation

## Requirements

- Raspberry Pi 5 (tested) with 64-bit Raspberry Pi OS
- Raspberry Pi 4 64-bit is provisional/community-supported
- network access during installation
- optional Raspberry Pi OS desktop for touchscreen kiosk mode
- supported NFC/scale hardware, or mock mode

## Install

```bash
git clone https://github.com/SLCMotor/filamenttracker-live-spool.git
cd filamenttracker-live-spool
sudo ./install.sh
```

Use `--scale-backend nau7802` or `--scale-backend hx711` to configure real hardware during a new install; omit it for an interactive choice or safe mock default.

Use `--no-kiosk` for a headless installation. On an unsupported development
machine, `--allow-unsupported` bypasses only the platform check.

The installer enables the local restart, reboot, and shutdown controls and adds
a narrowly scoped sudoers rule for those three appliance operations.

The installer is safe to rerun. It preserves existing external configuration and
calibration. A legacy calibration inside `software/pi-agent/data` is migrated
only when the external destination does not already exist.

## Select hardware

Edit `/etc/filamenttracker-live-spool/config.yaml`. For production NAU7802 and
PN532 operation, change the hardware mode/backend and both mock flags:

```yaml
hardware:
  device_mode: real
scale:
  backend: nau7802
  mock: false
nfc:
  mock: false
```

Restart and verify:

```bash
sudo systemctl restart live-spool-agent
curl --fail http://127.0.0.1:8001/health
curl --fail http://127.0.0.1:8001/status
i2cdetect -y 1
```

## Update

```bash
sudo ./scripts/update.sh
```

The checkout must be clean. Backups are stored below
`/var/backups/filamenttracker-live-spool/`.

## Uninstall

```bash
sudo ./uninstall.sh
```

Configuration and runtime/calibration data are preserved by default. Destructive
removal requires explicit `--remove-config` or `--remove-data` flags and a typed
confirmation (or `--yes` for deliberate automation).

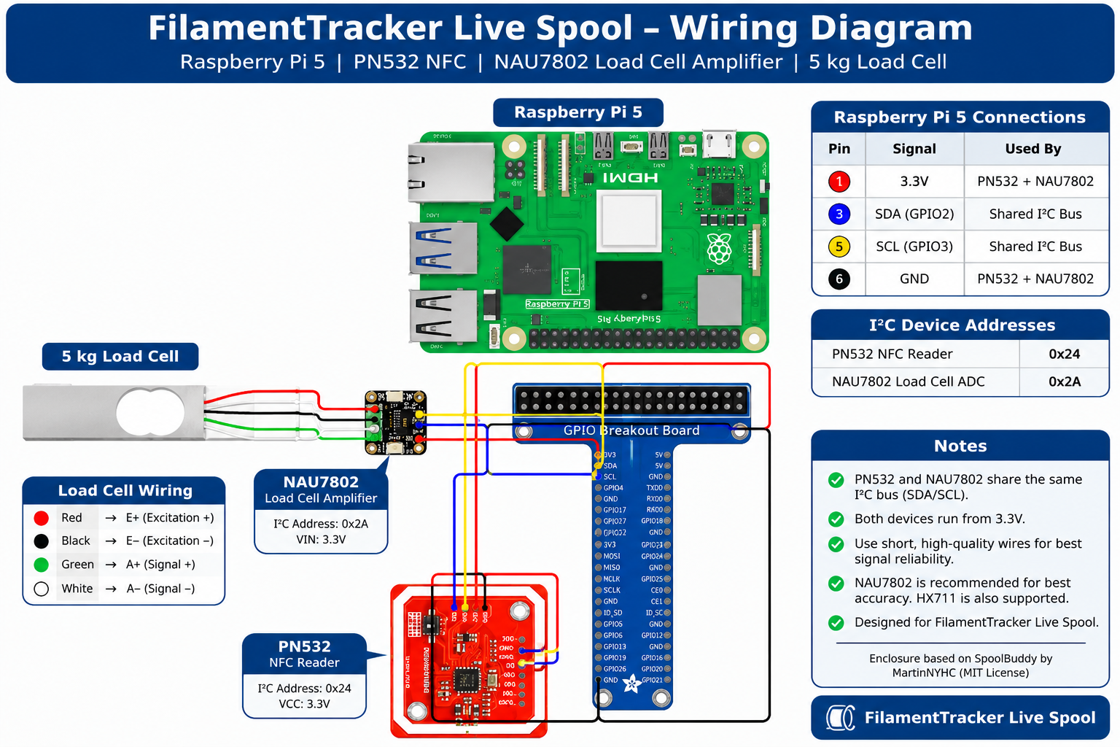
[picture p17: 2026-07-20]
hardware/docs/02_Wiring_Diagram.png

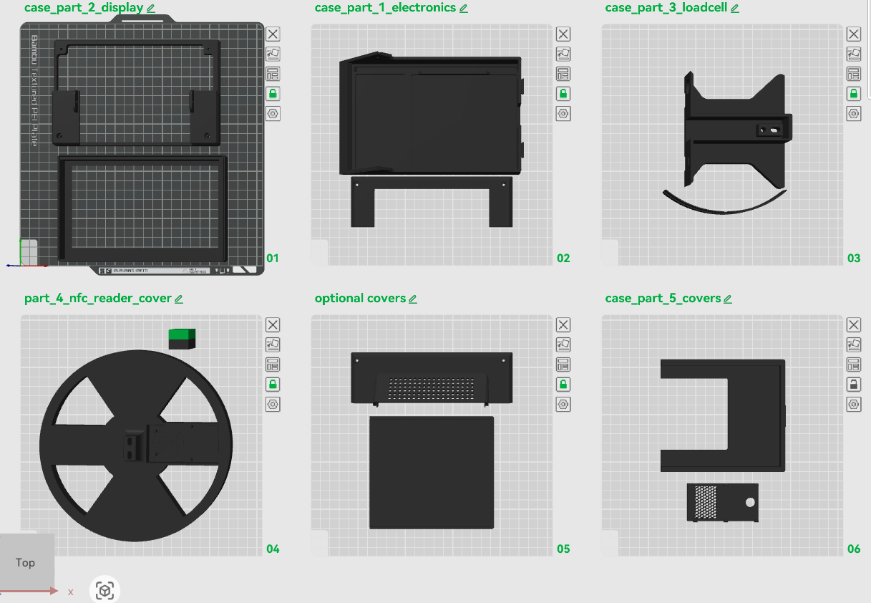
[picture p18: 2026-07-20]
hardware/docs/04_Print_Plates.png

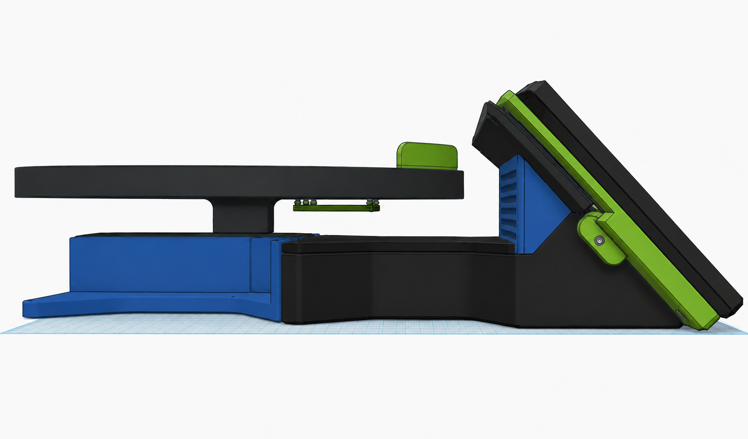
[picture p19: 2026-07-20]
hardware/docs/03_Assembly_Guide.png

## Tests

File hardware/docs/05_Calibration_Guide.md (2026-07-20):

# Calibration Guide

Calibration converts raw load-cell readings into grams. Perform it during the
initial build and repeat it whenever the load cell, scale ADC, mounting, or
platform mechanics change.

Calibration is stored outside the repository at:

```text
/var/lib/filamenttracker-live-spool/calibration.json
```

Installation and updates preserve this file.

## Before you begin

- Place Live Spool on a solid, level surface.
- Make sure the platform moves freely and does not touch the enclosure.
- Check that no cable pulls on the platform or load cell.
- Remove the spool and every other object from the platform.
- Use an accurately known reference weight. A 500 g or 1,000 g calibration
  weight is a practical choice for the 5 kg reference load cell.
- Allow the electronics and displayed reading to stabilize.
- Do not touch or lean on the appliance during measurements.

## Open the calibration wizard

Use the dashboard calibration shortcut, the technician menu, or open:

```text
http://<live-spool-host>:8001/calibration-wizard
```

Replace `<live-spool-host>` with the appliance hostname or local IP address.

## Calibration procedure

1. **Remove all weight.** Confirm that the platform is completely empty.
2. **Tare the scale.** Press **Tare** to record the unloaded zero offset.
3. **Add the reference weight.** Place it gently in the center of the platform.
4. **Enter its mass.** Select the matching preset or enter the exact value in
   grams. Enter the reference weight's known mass—not the displayed reading.
5. **Calibrate.** Wait for a stable measurement, then run the calibration step.
6. **Verify.** Confirm that the measured value is acceptably close to the known
   mass.
7. **Save.** Finish the wizard so the calibration is persisted across reboots.

## Verify the result

1. Remove the reference weight and confirm the reading returns close to zero.
2. Place the weight in the center again and allow the reading to settle.
3. Compare the displayed value with the known mass.
4. Repeat this test two or three times.

A small amount of variation is normal. Large, inconsistent, or steadily
changing errors usually indicate a mechanical or wiring problem rather than a
calibration-value problem.

## Troubleshooting

### Reading drifts while untouched

- Check that the platform and load cell do not touch the enclosure.
- Make sure wiring is not applying force to the moving assembly.
- Move the appliance away from vibration, drafts, or an unstable work surface.
- Allow the electronics to warm up and repeat tare.

### Calibration fails or reports the wrong value

- Confirm the entered reference mass is correct and expressed in grams.
- Make sure the platform was empty during tare.
- Center the reference weight and wait for a stable reading.
- Repeat the complete process rather than calibrating over an old tare.

### Reading is unstable

- Inspect load-cell wiring and tighten loose terminals.
- Check load-cell and platform fasteners without mechanically binding the beam.
- Confirm the selected scale backend matches the installed ADC.
- Keep NFC and other wiring clear of the weighing mechanism.

### No weight is detected

For NAU7802 installations, verify that address `0x2A` appears:

```bash
i2cdetect -y 1
```

Then inspect service and hardware status:

```bash
curl --fail http://127.0.0.1:8001/status
curl --fail http://127.0.0.1:8001/weight
sudo journalctl -u live-spool-agent -n 100 --no-pager
```

For HX711 installations, recheck the configured data and clock GPIO pins.

## Recalibrate after hardware changes

Always recalibrate after changing the load cell, ADC, platform, mounting
hardware, or anything that changes the mechanical load path. A normal software
update does not require recalibration.

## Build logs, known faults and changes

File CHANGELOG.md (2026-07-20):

# Changelog

All notable changes are documented here. This project follows Semantic
Versioning and the Keep a Changelog format.

## [Unreleased]

### Fixed

- Raspberry Pi reboot and shutdown controls now use installed, narrowly scoped
  authorization and report disabled or failed requests instead of displaying a
  false success state.
- The root-run updater now performs Git operations as the checkout owner so SSH
  credentials and host verification work correctly.
- Added README and hardware-guide instructions for opening the hidden Technician
  Menu from the touchscreen header.

## [0.1.0] - 2026-07-20

Initial public preview of the FilamentTracker Live Spool Raspberry Pi appliance.

### Added

- external appliance configuration and runtime-data paths
- preservation-first installer, updater, uninstaller, systemd unit, and kiosk setup
- mock-hardware tests and GitHub Actions quality checks
- public release, security, contribution, and hardware documentation
- publication-safe appliance, interface, component, and wiring photographs
- printable enclosure files, build guides, BOM, and calibration documentation
- CC BY 4.0 attribution and modification record for the derivative enclosure

### Changed

- safe mock hardware is now the development and first-install default
- mock and system-control routes are conditionally exposed
- PN532 address, API listener, scale pins/backend, runtime path, and logging are configurable

### Supported hardware and integration

- PN532, NAU7802, HX711, and Bambu RFID reading
- touchscreen dashboard, calibration, diagnostics, and local REST API
- FilamentTracker Android and FilamentTracker Server workflows

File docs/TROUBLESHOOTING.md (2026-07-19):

# Troubleshooting

## Service or API unavailable

```bash
sudo systemctl status live-spool-agent --no-pager -l
sudo journalctl -u live-spool-agent -n 100 --no-pager
curl -v http://127.0.0.1:8001/health
```

Verify paths in the installed unit with `systemctl cat live-spool-agent` and check
YAML indentation in `/etc/filamenttracker-live-spool/config.yaml`.

## I2C hardware unavailable

```bash
ls -l /dev/i2c-1
i2cdetect -y 1
groups
```

Expected addresses are PN532 `24` and NAU7802 `2a`. Power down before changing
wiring. Confirm the PN532 board is physically switched/jumpered to I2C mode.
Both devices may share SDA/SCL but require unique addresses and a common ground.

## Incorrect or unstable weight

- ensure the platform is not touching the enclosure
- check that the load direction is consistent
- verify all four bridge connections
- increase sample counts only after checking mechanical noise
- recalibrate with an accurate known weight near the normal operating range
- swap `A+` and `A-` if force produces the opposite sign

## Kiosk does not start

Run the launcher from the desktop user session and inspect errors:

```bash
software/pi-agent/scripts/start-dashboard-kiosk.sh
```

Confirm Chromium is installed and the desktop user's autostart file exists at
`~/.config/autostart/live-spool-kiosk.desktop`.

## Android or Server cannot connect

Confirm the client and Pi are on the same trusted LAN, use the Pi's current local
address and configured port, and do not use `localhost` from the Android device.
Do not expose the port through router forwarding.

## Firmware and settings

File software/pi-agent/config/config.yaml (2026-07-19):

# Safe development defaults. The installer creates an appliance copy under /etc.
app:
  name: "FilamentTracker Live Spool"
  version: "0.1.0"
  environment: "development"
server:
  host: "0.0.0.0"
  port: 8001
  log_level: "info"
device:
  name: "Live Spool"
  location: ""
runtime:
  data_dir: "data"
hardware:
  device_mode: "mock"
scale:
  enabled: true
  backend: "mock"
  mock: true
  hx711:
    data_pin: 5
    clock_pin: 6
    gain: 128
    samples: 15
  nau7802:
    address: 0x2A
    channel: 1
    gain: 128
    poll_rate: 10
    samples: 15
    stable_stddev: 1000
nfc:
  enabled: true
  mock: true
  pn532:
    address: 0x24
admin:
  # These controls are intended only for a trusted local appliance.
  system_controls_enabled: false

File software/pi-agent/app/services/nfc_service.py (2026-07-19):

from __future__ import annotations

import json
import threading
import time
from typing import Any, Callable, Optional

from app.services.bambu_rfid import read_bambu_rfid
from app.core.config import config

try:
    import board
    import busio
    from adafruit_pn532.i2c import PN532_I2C
except Exception:
    board = None
    busio = None
    PN532_I2C = None

FILAMENT_TRACKER_MIME_TYPE = b"application/vnd.com.slcmotor.filamenttracker.filament"


class NFCService:
    def __init__(self) -> None:
        self.pn532 = None
        self.error: Optional[str] = None
        self._io_lock = threading.RLock()
        self._connect()

    def _connect(self) -> None:
        if board is None or busio is None or PN532_I2C is None:
            self.error = "PN532 libraries not available"
            return

        try:
            i2c = busio.I2C(board.SCL, board.SDA)
            self.pn532 = PN532_I2C(i2c, debug=False, address=config.pn532_address)
            self.pn532.SAM_configuration()
            self.error = None
        except Exception as exc:
            self.pn532 = None
            self.error = str(exc)

    def read(self) -> dict:
        with self._io_lock:
            return self._read_locked()

    def _read_locked(self) -> dict:
        if self.pn532 is None:
            self._connect()

        if self.pn532 is None:
            return self._empty_status(connected=False, error=self.error)

        try:
            uid = self.pn532.read_passive_target(timeout=0.5)

            if uid is None:
                return self._empty_status(connected=True)

            bambu_tag = self._read_bambu_rfid(uid) if self._is_bambu_candidate_uid(uid) else None
            data = None if bambu_tag and bambu_tag.get("isBambuTag") else self._read_ntag_text()
            filament_tracker_tag = self._parse_filament_tracker_payload(data)

            return {
                "connected": True,
                "tagPresent": True,
                "tagId": uid.hex().upper(),
                "data": data,
                "tag": filament_tracker_tag or self._bambu_tag_summary(bambu_tag),
                "tagType": self._tag_type(filament_tracker_tag, bambu_tag),
                "bambu": bambu_tag,
                "error": None,
            }

        except Exception as exc:
            self.error = str(exc)
            self.pn532 = None
            return self._empty_status(connected=False, error=self.error)

    def erase(self) -> dict:
        with self._io_lock:
            return self._erase_locked()

    def _erase_locked(self) -> dict:
        if self.pn532 is None:
            self._connect()

        if self.pn532 is None:
            return {
                "success": False,
                "connected": False,
                "tagPresent": False,
                "tagId": None,
                "message": self.error or "NFC reader unavailable",
            }

        try:
            uid = self.pn532.read_passive_target(timeout=8)

            if uid is None:
                return {
                    "success": False,
                    "connected": True,
                    "tagPresent": False,
                    "tagId": None,
                    "message": "No tag detected",
                }

            tag_id = uid.hex().upper()

            # Safe logical erase for NTAG: replace user data with an empty NDEF message.
            # Avoids touching lock/configuration pages.
            self.pn532.ntag2xx_write_block(4, bytes([0x03, 0x00, 0xFE, 0x00]))

            for page in range(5, 40):
                try:
                    self.pn532.ntag2xx_write_block(page, bytes([0x00, 0x00, 0x00, 0x00]))
                except Exception:
                    break

            return {
                "success": True,
                "connected": True,
                "tagPresent": True,
                "tagId": tag_id,
                "message": "Erase successful",
            }

        except Exception as exc:
            self.error = str(exc)
            self.pn532 = None
            return {
                "success": False,
                "connected": False,
                "tagPresent": False,
                "tagId": None,
                "message": self.error,
            }

    def write_payload(
        self,
        payload: dict[str, Any],
        timeout_seconds: int = 60,
        progress_callback: Optional[Callable[[str, str, Optional[str]], None]] = None,
        cancel_callback: Optional[Callable[[], bool]] = None,
    ) -> dict:
        with self._io_lock:
            return self._write_payload_locked(payload, timeout_seconds, progress_callback, cancel_callback)

    def _write_payload_locked(
        self,
        payload: dict[str, Any],
        timeout_seconds: int,
        progress_callback: Optional[Callable[[str, str, Optional[str]], None]],
        cancel_callback: Optional[Callable[[], bool]],
    ) -> dict:
        if self.pn532 is None:
            self._connect()

        if self.pn532 is None:
            return {
                "success": False,
                "connected": False,
                "tagPresent": False,
                "tagId": None,
                "message": self.error or "NFC reader unavailable",
                "errorCode": "reader_unavailable",
            }

        try:
            deadline = time.monotonic() + max(1, timeout_seconds)
            uid = None

            while time.monotonic() < deadline:
                if cancel_callback and cancel_callback():
                    return {
                        "success": False,
                        "connected": True,
                        "tagPresent": False,
                        "tagId": None,
                        "message": "Write canceled",
                        "errorCode": "canceled",
                    }

                uid = self.pn532.read_passive_target(timeout=0.5)
                if uid is not None:
                    break

            if uid is None:
                return {
                    "success": False,
                    "connected": True,
                    "tagPresent": False,
                    "tagId": None,
                    "message": "No tag detected",
                    "errorCode": "timeout",
                }

            tag_id = uid.hex().upper()
            if progress_callback:
                progress_callback("writing", "Writing...", tag_id)

            text_payload = json.dumps(payload, separators=(",", ":"), ensure_ascii=False)
            ndef_bytes = self._build_ndef_mime_tlv(text_payload)

            page_count = (len(ndef_bytes) + 3) // 4
            if page_count > 126:
                return {
                    "success": False,
                    "connected": True,
                    "tagPresent": True,
                    "tagId": tag_id,
                    "message": "NFC payload is too large for this tag.",
                    "errorCode": "tag_too_small",
                }
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

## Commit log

2026-06-26 Add device abstraction and mock scale
2026-06-26 Add mock NFC device
2026-06-26 Add calibration API and mock scale controls
2026-06-26 Persist calibration settings
2026-06-26 Ignore runtime calibration data
2026-06-26 Move mock scale into device layer
2026-06-26 Refactor NFC device layer
2026-06-26 Add configurable device mode
2026-06-29 Add current spool state endpoint
2026-06-29 Persist calibration storage
2026-06-29 Dashboard V1.2 UI polish
    - New appliance-style dashboard layout
    - Premium spool information card
    - Circular filament color swatch
    - Brand badge
    - Enhanced spool visualization
    - Footer status cards
    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
2026-07-01 Add shared application shell and improve calibration navigation
2026-07-02 Stabilize status endpoint and add system metrics
    [status_service.py]
2026-07-03 Stabilize PN532 Bambu RFID reads
    [bambu_rfid.py, nfc_service.py]
2026-07-03 Skip Bambu probing for NTAG-style UIDs
    [nfc_service.py]
2026-07-03 Stabilize HX711 calibration flow
    [config.yaml, hx711_scale.py]
2026-07-03 Relax calibration wizard for hardware scales
2026-07-03 Clamp dashboard scale drift near zero
2026-07-03 Clarify blank NFC state and expose calibration
2026-07-19 Document Raspberry Pi platform dependencies
2026-07-20 Add printable enclosure and hardware build documentation
    [FilamentTracker_Live_Spool.stl]
2026-07-20 Fix Raspberry Pi reboot and shutdown controls
